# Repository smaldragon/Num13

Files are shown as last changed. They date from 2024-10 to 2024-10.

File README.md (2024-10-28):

# Num13

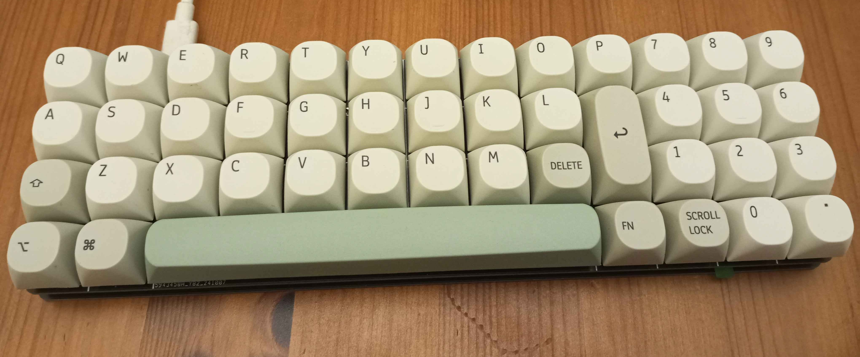
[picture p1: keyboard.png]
Photo of the keyboard in person


**Num13** is a 45-key compact ortholinear mechanical keyboard which includes a **Num**pad and is **13**Ux4U in size, which I designed for my own personal use.

The build is composed of 2 PCBs, the **top** pcb includes the key matrix (MX switches or low-profile Redragon switches w/ plate stabs), while the **bottom** includes the keyboard controller (a pi pico), a status led (rgb on the rB revision included here), and serves as the base of the keyboard structure itself.

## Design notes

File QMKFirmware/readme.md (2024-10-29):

# num13

num13

*A short description of the keyboard/project*

* Keyboard Maintainer: [smaldragon](https://github.com/smaldragon)
* Hardware Supported: *The PCBs, controllers supported*
* Hardware Availability: *Links to where you can find this hardware*

Make example for this keyboard (after setting up your build environment):

    make num13:default

Flashing example for this keyboard:

    make num13:default:flash

See the [build environment setup](https://docs.qmk.fm/#/getting_started_build_tools) and the [make instructions](https://docs.qmk.fm/#/getting_started_make_guide) for more information. Brand new to QMK? Start with our [Complete Newbs Guide](https://docs.qmk.fm/#/newbs).

## Bootloader

Enter the bootloader in 3 ways:

* **Bootmagic reset**: Hold down the key at (0,0) in the matrix (usually the top left key or Escape) and plug in the keyboard
* **Physical reset button**: Briefly press the button on the back of the PCB - some may have pads you must short instead
* **Keycode in layout**: Press the key mapped to `QK_BOOT` if it is available

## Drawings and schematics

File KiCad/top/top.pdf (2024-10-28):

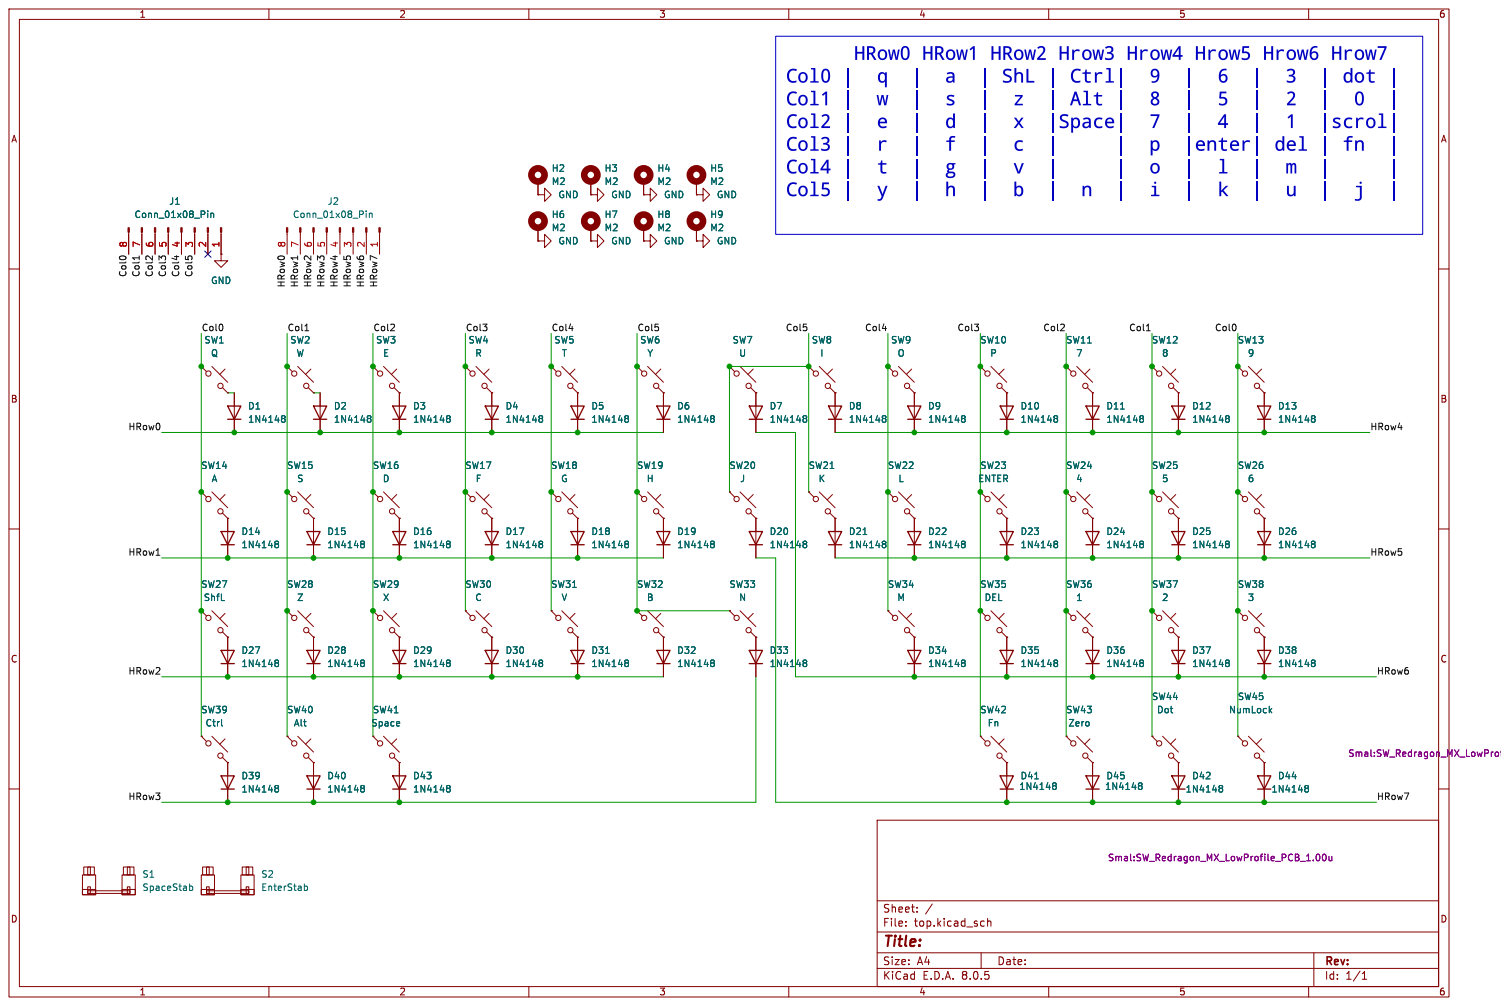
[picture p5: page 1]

Id: 1/1 Title: File: top.kicad_sch Sheet: /

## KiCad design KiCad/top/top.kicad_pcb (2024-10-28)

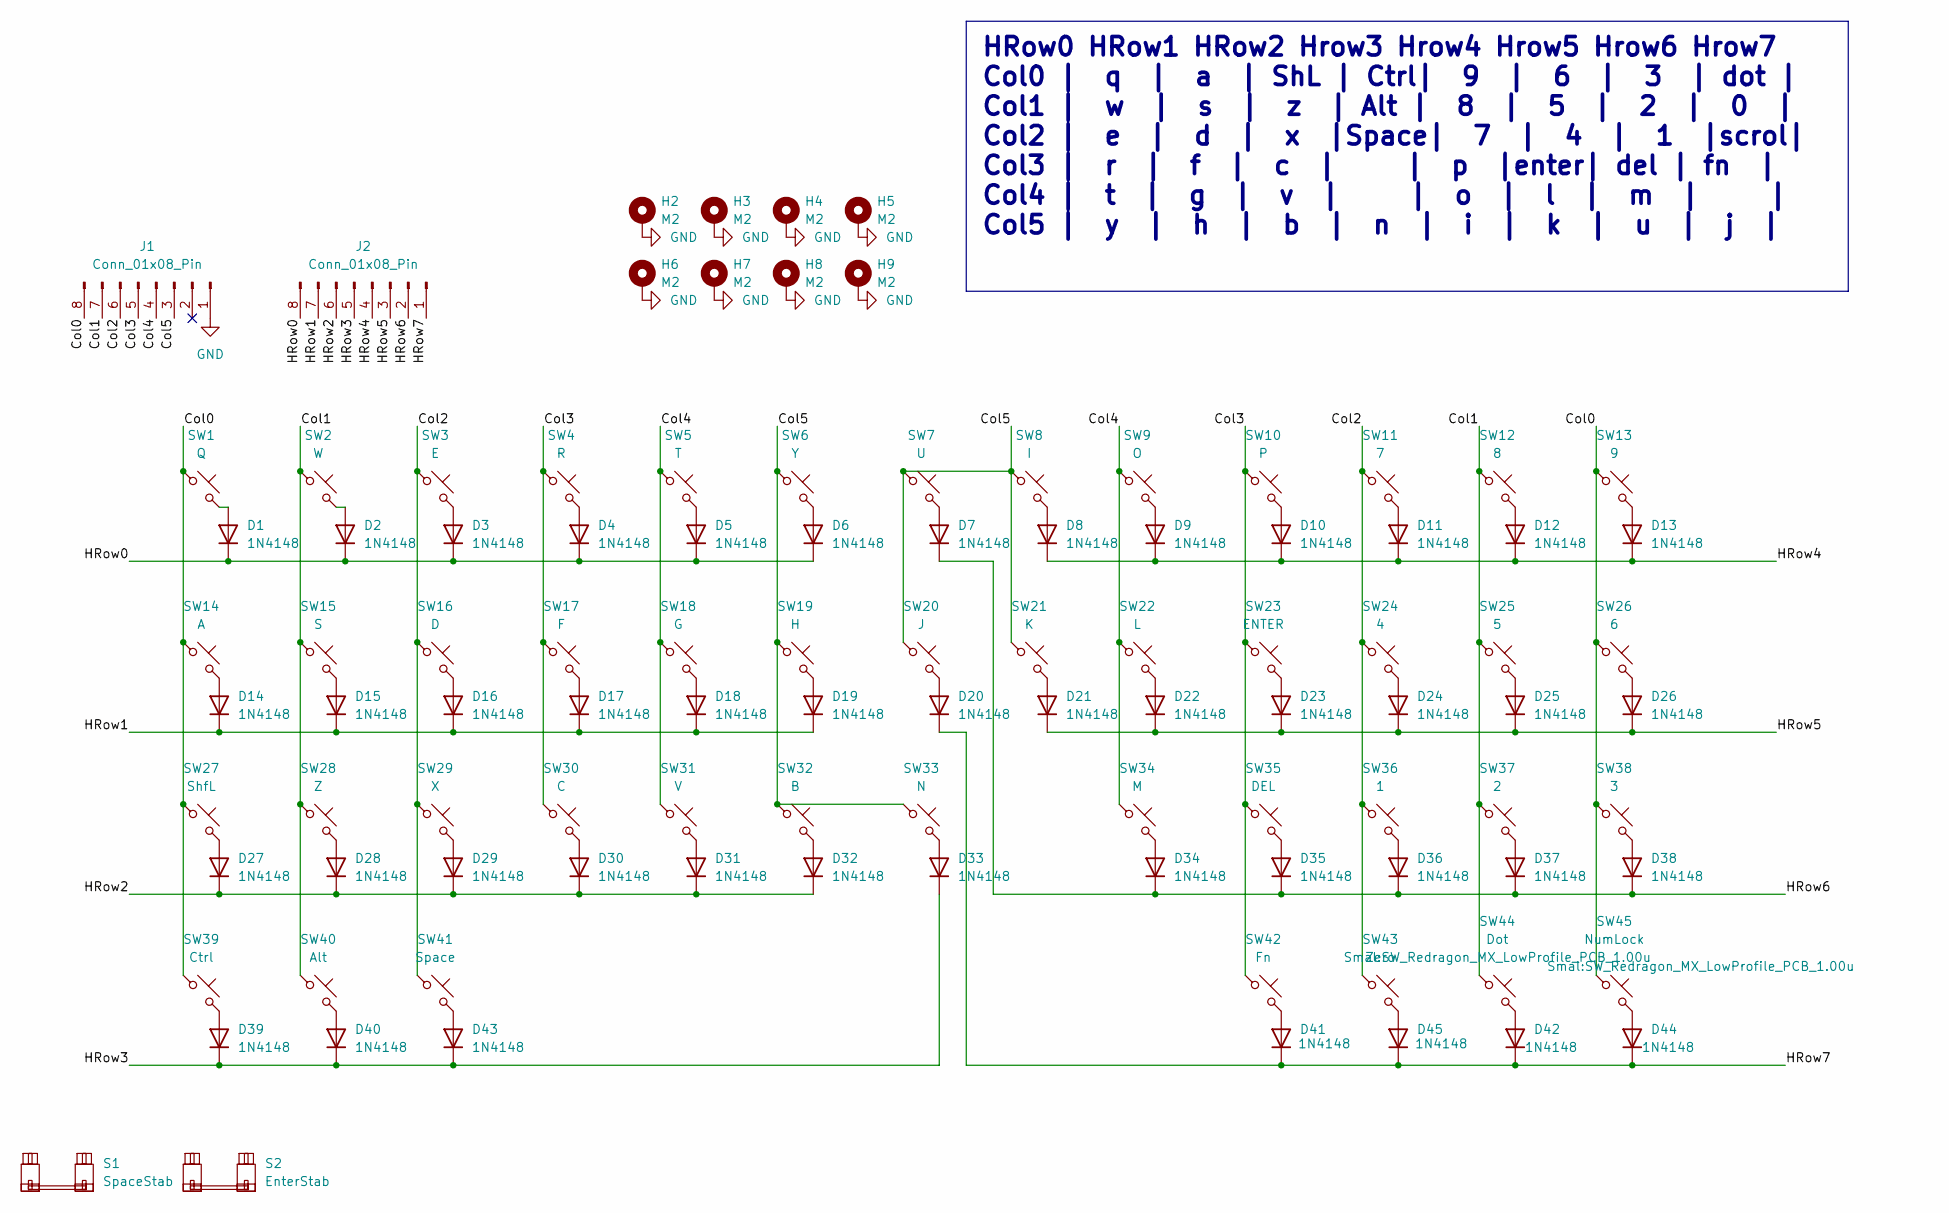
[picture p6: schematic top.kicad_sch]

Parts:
D1, D2, D3, D4, D5, D6, D7, D8, D9, D10, D11, D12, D13, D14, D15, D16, D17, D18, D19, D20, D21, D22, D23, D24, D25, D26, D27, D28, D29, D30, D31, D32, D33, D34, D35, D36, D37, D38, D39, D40, D41, D42, D43, D44, D45: 1N4148; D_DO-35_SOD27_P7.62mm_Horizontal
H2, H3, H4, H5, H6, H7, H8, H9: M2; MountingHole_2.2mm_M2_Pad
J1, J2: Conn_01x08_Pin; PinHeader_1x08_P2.54mm_Vertical
S1: SpaceStab; ks27_7u_pcb_cherry_plate
S2: EnterStab; ks27_2u_pcb_cherry_plate_stab
SW1: Q; SW_Redragon_MX_LowProfile_PCB_1.00u
SW2: W; SW_Redragon_MX_LowProfile_PCB_1.00u
SW3: E; SW_Redragon_MX_LowProfile_PCB_1.00u
SW4: R; SW_Redragon_MX_LowProfile_PCB_1.00u
SW5: T; SW_Redragon_MX_LowProfile_PCB_1.00u
SW6: Y; SW_Redragon_MX_LowProfile_PCB_1.00u
SW7: U; SW_Redragon_MX_LowProfile_PCB_1.00u
SW8: I; SW_Redragon_MX_LowProfile_PCB_1.00u
SW9: O; SW_Redragon_MX_LowProfile_PCB_1.00u
SW10: P; SW_Redragon_MX_LowProfile_PCB_1.00u
SW11: 7; SW_Redragon_MX_LowProfile_PCB_1.00u
SW12: 8; SW_Redragon_MX_LowProfile_PCB_1.00u
SW13: 9; SW_Redragon_MX_LowProfile_PCB_1.00u
SW14: A; SW_Redragon_MX_LowProfile_PCB_1.00u
SW15: S; SW_Redragon_MX_LowProfile_PCB_1.00u
SW16: D; SW_Redragon_MX_LowProfile_PCB_1.00u
SW17: F; SW_Redragon_MX_LowProfile_PCB_1.00u
SW18: G; SW_Redragon_MX_LowProfile_PCB_1.00u
SW19: H; SW_Redragon_MX_LowProfile_PCB_1.00u
SW20: J; SW_Redragon_MX_LowProfile_PCB_1.00u
SW21: K; SW_Redragon_MX_LowProfile_PCB_1.00u
SW22: L; SW_Redragon_MX_LowProfile_PCB_1.00u
SW23: ENTER; SW_Redragon_MX_LowProfile_PCB_2.00u
SW24: 4; SW_Redragon_MX_LowProfile_PCB_1.00u
SW25: 5; SW_Redragon_MX_LowProfile_PCB_1.00u
SW26: 6; SW_Redragon_MX_LowProfile_PCB_1.00u
SW27: ShfL; SW_Redragon_MX_LowProfile_PCB_1.00u
SW28: Z; SW_Redragon_MX_LowProfile_PCB_1.00u
SW29: X; SW_Redragon_MX_LowProfile_PCB_1.00u
SW30: C; SW_Redragon_MX_LowProfile_PCB_1.00u
SW31: V; SW_Redragon_MX_LowProfile_PCB_1.00u
SW32: B; SW_Redragon_MX_LowProfile_PCB_1.00u
SW33: N; SW_Redragon_MX_LowProfile_PCB_1.00u
SW34: M; SW_Redragon_MX_LowProfile_PCB_1.00u
SW35: DEL; SW_Redragon_MX_LowProfile_PCB_1.00u
SW36: 1; SW_Redragon_MX_LowProfile_PCB_1.00u
SW37: 2; SW_Redragon_MX_LowProfile_PCB_1.00u
SW38: 3; SW_Redragon_MX_LowProfile_PCB_1.00u
SW39: Ctrl; SW_Redragon_MX_LowProfile_PCB_1.00u
SW40: Alt; SW_Redragon_MX_LowProfile_PCB_1.00u
SW41: Space; SW_Redragon_MX_LowProfile_PCB_7.00u
SW42: Fn; SW_Redragon_MX_LowProfile_PCB_1.00u
SW43: Zero; SW_Redragon_MX_LowProfile_PCB_1.00u
SW44: Dot; SW_Redragon_MX_LowProfile_PCB_1.00u
SW45: NumLock; SW_Redragon_MX_LowProfile_PCB_1.00u

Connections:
/Col0: J1.8, SW1.1, SW13.1, SW14.1, SW26.1, SW27.1, SW38.1, SW39.1, SW45.1
/Col1: J1.7, SW2.1, SW12.1, SW15.1, SW25.1, SW28.1, SW37.1, SW40.1, SW44.1
/Col2: J1.6, SW3.1, SW11.1, SW16.1, SW24.1, SW29.1, SW36.1, SW41.1, SW43.1
/Col3: J1.5, SW4.1, SW10.1, SW17.1, SW23.1, SW30.1, SW35.1, SW42.1
/Col4: J1.4, SW5.1, SW9.1, SW18.1, SW22.1, SW31.1, SW34.1
/Col5: J1.3, SW6.1, SW7.1, SW8.1, SW19.1, SW20.1, SW21.1, SW32.1, SW33.1
/HRow0: D1.1 (K), D2.1 (K), D3.1 (K), D4.1 (K), D5.1 (K), D6.1 (K), J2.8
/HRow1: D14.1 (K), D15.1 (K), D16.1 (K), D17.1 (K), D18.1 (K), D19.1 (K), J2.7
/HRow2: D27.1 (K), D28.1 (K), D29.1 (K), D30.1 (K), D31.1 (K), D32.1 (K), J2.6
/HRow3: D33.1 (K), D39.1 (K), D40.1 (K), D43.1 (K), J2.5
/HRow4: D8.1 (K), D9.1 (K), D10.1 (K), D11.1 (K), D12.1 (K), D13.1 (K), J2.4
/HRow5: D21.1 (K), D22.1 (K), D23.1 (K), D24.1 (K), D25.1 (K), D26.1 (K), J2.3
/HRow6: D7.1 (K), D34.1 (K), D35.1 (K), D36.1 (K), D37.1 (K), D38.1 (K), J2.2
/HRow7: D20.1 (K), D41.1 (K), D42.1 (K), D44.1 (K), D45.1 (K), J2.1
GND: H2.1, H3.1, H4.1, H5.1, H6.1, H7.1, H8.1, H9.1, J1.1
unnamed: D1.2 (A), SW1.2
unnamed: D2.2 (A), SW2.2
unnamed: D3.2 (A), SW3.2
unnamed: D4.2 (A), SW4.2
unnamed: D5.2 (A), SW5.2
unnamed: D6.2 (A), SW6.2
unnamed: D7.2 (A), SW7.2
unnamed: D8.2 (A), SW8.2
unnamed: D9.2 (A), SW9.2
unnamed: D10.2 (A), SW10.2
unnamed: D11.2 (A), SW11.2
unnamed: D12.2 (A), SW12.2
unnamed: D13.2 (A), SW13.2
unnamed: D14.2 (A), SW14.2
unnamed: D15.2 (A), SW15.2
unnamed: D16.2 (A), SW16.2
unnamed: D17.2 (A), SW17.2
unnamed: D18.2 (A), SW18.2
unnamed: D19.2 (A), SW19.2
unnamed: D20.2 (A), SW20.2
unnamed: D21.2 (A), SW21.2
unnamed: D22.2 (A), SW22.2
unnamed: D23.2 (A), SW23.2
unnamed: D24.2 (A), SW24.2
unnamed: D25.2 (A), SW25.2
unnamed: D26.2 (A), SW26.2
unnamed: D27.2 (A), SW27.2
unnamed: D28.2 (A), SW28.2
unnamed: D29.2 (A), SW29.2
unnamed: D30.2 (A), SW30.2
unnamed: D31.2 (A), SW31.2
unnamed: D32.2 (A), SW32.2
unnamed: D33.2 (A), SW33.2
unnamed: D34.2 (A), SW34.2
unnamed: D35.2 (A), SW35.2
unnamed: D36.2 (A), SW36.2
unnamed: D37.2 (A), SW37.2
unnamed: D38.2 (A), SW38.2
unnamed: D39.2 (A), SW39.2
unnamed: D40.2 (A), SW40.2
unnamed: D41.2 (A), SW42.2
unnamed: D42.2 (A), SW44.2
unnamed: D43.2 (A), SW41.2
unnamed: D44.2 (A), SW45.2
unnamed: D45.2 (A), SW43.2

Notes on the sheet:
HRow0 HRow1 HRow2 Hrow3 Hrow4 Hrow5 Hrow6 Hrow7 Col0 | q | a | ShL | Ctrl| 9 | 6 | 3 | dot | Col1 | w | s | z | Alt | 8 | 5 | 2 | 0 | Col2 | e | d | x |Space| 7 | 4 | 1 |scrol| Col3 | r | f | c | | p |enter| del | fn | Col4 | t | g | v | | o | l | m | | Col5 | y | h | b | n | i | k | u | j |

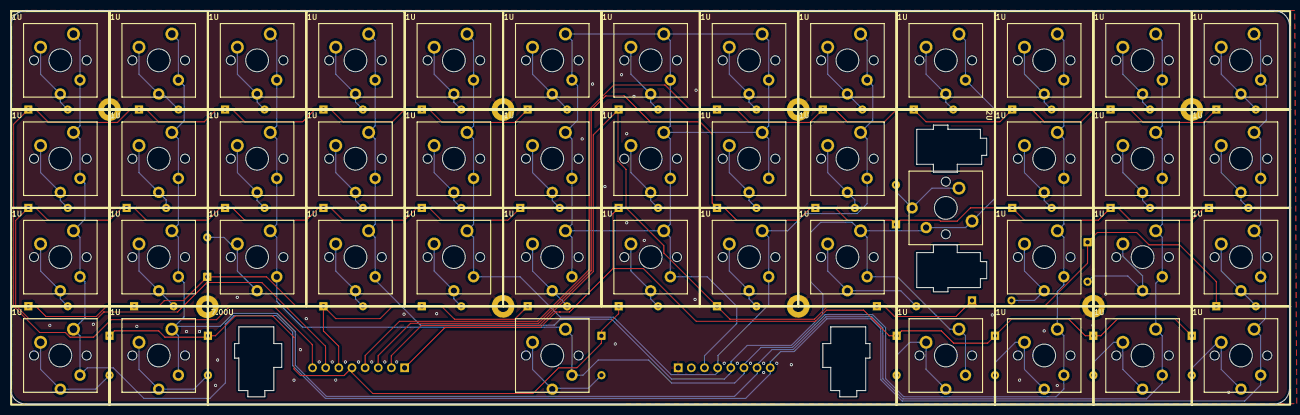
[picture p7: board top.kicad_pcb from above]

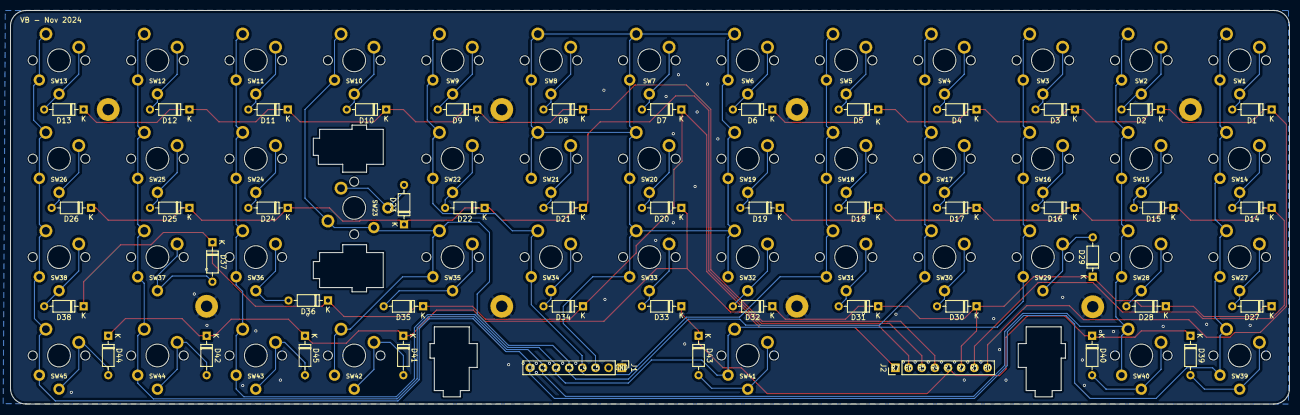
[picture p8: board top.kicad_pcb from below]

Board: 2 copper layers, 247.0 x 76.0 mm, 102 parts (47 on the bottom side), 60 nets.

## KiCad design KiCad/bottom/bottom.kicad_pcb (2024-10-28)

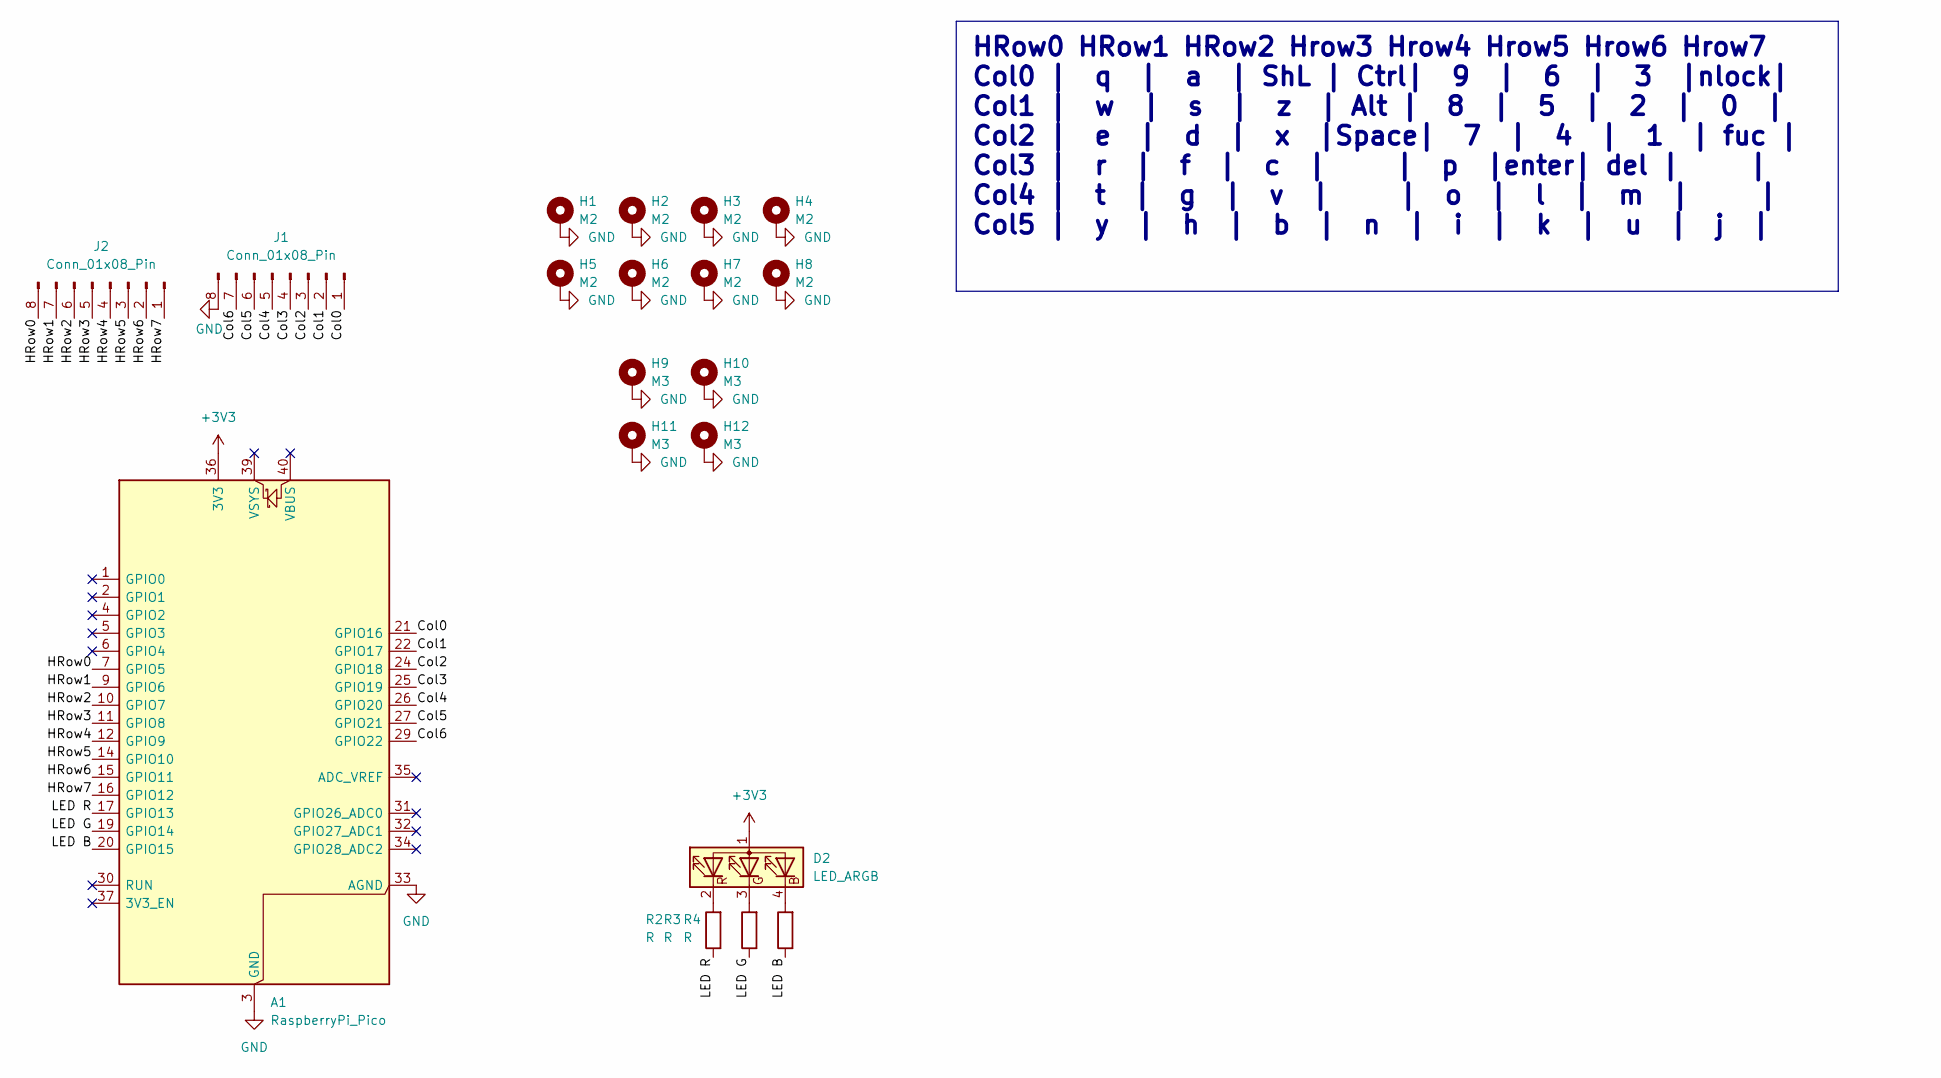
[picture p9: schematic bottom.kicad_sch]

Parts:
A1: RaspberryPi_Pico; RaspberryPi_Pico_Common_SMD
D2: LED_ARGB; ARGB horizontal
H1, H2, H3, H4, H5, H6, H7, H8: M2; MountingHole_2.2mm_M2_Pad
H9, H10, H11, H12: M3; MountingHole_3.2mm_M3_Pad
J1, J2: Conn_01x08_Pin; Harwin_M20-89008xx_1x08_P2.54mm_Horizontal
R2, R3, R4: R; R_0805_2012Metric

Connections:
+3V3: A1.36 (3V3), D2.1 (A)
/Col0: A1.21 (GPIO16), J1.1
/Col1: A1.22 (GPIO17), J1.2
/Col2: A1.24 (GPIO18), J1.3
/Col3: A1.25 (GPIO19), J1.4
/Col4: A1.26 (GPIO20), J1.5
/Col5: A1.27 (GPIO21), J1.6
/Col6: A1.29 (GPIO22), J1.7
/HRow0: A1.7 (GPIO5), J2.8
/HRow1: A1.9 (GPIO6), J2.7
/HRow2: A1.10 (GPIO7), J2.6
/HRow3: A1.11 (GPIO8), J2.5
/HRow4: A1.12 (GPIO9), J2.4
/HRow5: A1.14 (GPIO10), J2.3
/HRow6: A1.15 (GPIO11), J2.2
/HRow7: A1.16 (GPIO12), J2.1
/LED B: A1.20 (GPIO15), R4.1
/LED G: A1.19 (GPIO14), R3.1
/LED R: A1.17 (GPIO13), R2.1
GND: A1.3 (GND), A1.8 (GND), A1.13 (GND), A1.18 (GND), A1.23 (GND), A1.28 (GND), A1.33 (AGND), A1.38 (GND), H1.1, H2.1, H3.1, H4.1, H5.1, H6.1, H7.1, H8.1, H9.1, H10.1, H11.1, H12.1, J1.8
unnamed: D2.4 (BK), R4.2
unnamed: D2.3 (GK), R3.2
unnamed: D2.2 (RK), R2.2

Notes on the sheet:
HRow0 HRow1 HRow2 Hrow3 Hrow4 Hrow5 Hrow6 Hrow7 Col0 | q | a | ShL | Ctrl| 9 | 6 | 3 |nlock| Col1 | w | s | z | Alt | 8 | 5 | 2 | 0 | Col2 | e | d | x |Space| 7 | 4 | 1 | fuc | Col3 | r | f | c | | p |enter| del | | Col4 | t | g | v | | o | l | m | | Col5 | y | h | b | n | i | k | u | j |

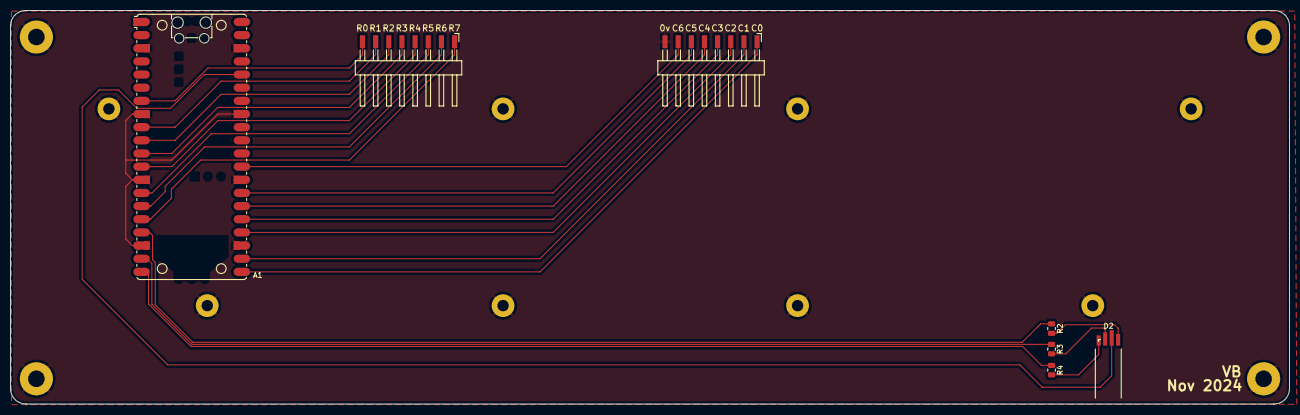
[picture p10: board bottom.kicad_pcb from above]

Board: 2 copper layers, 247.0 x 76.0 mm, 19 parts (0 on the bottom side), 23 nets.

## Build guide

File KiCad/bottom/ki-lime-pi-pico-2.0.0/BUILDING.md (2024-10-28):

**Instructions for building from source**
===========================================

> *Note that this project was largely leveraged for becoming more familiar with various aspects of KiCad, FreeCAD, and the Raspberry Pi Pico, and certain files may use exploratory workflows as a result.*

&nbsp;

# Development Environment

  Parametric models created in [FreeCAD 0.20.2](https://github.com/FreeCAD/FreeCAD/releases/tag/0.20.2) with the [KiCad StepUp 10.7.7](https://github.com/easyw/kicadStepUpMod/tree/5dfb0eb7093ab7f67d0f91c9bbae6fb78de93d46) workbench addon

  Exported VRML models modified in [VSCodium 1.74.3](https://github.com/VSCodium/vscodium/releases/tag/1.74.3.23010)

  KiCad symbols and footprints created using KiCad 6.0.10 through 8.0.3 and finalized using [KiCad 8.0.3](https://github.com/KiCad/kicad-source-mirror/releases/tag/8.0.3)

&nbsp;

# Symbols and Footprints

  KiCad symbols and footprints are already in the appropriate directories, so nothing needs to be done to prepare them for export.

&nbsp;

# Models

<details><summary>Regarding parametric colours</summary>
  
  > *Model faces are parametrically coloured via boolean operations between parts of varying diffuse colours.  To alter source colours for the board, see `Parametric_Source > Boards_Source > Parametric Board Colour Sources` in the `Tree view` panel and modify each Body's `Appearance`.  To alter source colours for components, be sure to modify the `Appearance` of the source Bodies **directly**, which are contained within the compounds/part containers in `Parametric_Source > Pico_Components_Source`.  Modifying the `Appearance` of the compounds/part containers or setting parts' face colours with `Set Colors...` will **not** parametrically populate.*
  >
  > *Note that as of FreeCAD 0.20.2 changing the sources of the colours does not automatically populate down all the dependent objects.  To get around this if you make any colour changes, when you are ready to export be sure to recompute the entire document as detailed below.  This should successfully populate the parametric colours across all dependent objects.*
  
</details>

  ### General

  - Open the models source file at `.../ki-lime-pi-pico/models/RaspberryPi_Pico_Variations.FCStd` in FreeCAD

  - In FreeCAD's `Tree view` panel, `right-click` on the root document name `RaspberryPi_Pico_Variations` and select `Mark to recompute`

  - Click `Edit > Refresh` (or press `F5`) to recompute the entire document

  ### VRML

  - Enter the KiCad StepUp addon workbench from the drop-down menu at the top of the window

  - In FreeCAD's `Tree view` panel, locate the contents of the folder `Export > KiCad Model Outputs > VRML - Manually Coloured Clones`

  - Select the `Clone` you wish to export to a VRML file for KiCad (for example: `RaspberryPi_Pico`)
    <details><summary>Additional information regarding clones and colours</summary>
      
      > *KiCad StepUp provides a selection of fully-featured materials that can be exported to VRML files.  Although the selection is limited, it provides convenient labelling of materials that can be edited later.  I have created `Clones` of each variation (which as of FreeCAD 0.20.2 do **not** parametrically preserve colour) and pre-set each face colour to align with colours defined within KiCad StepUp.*
      >
      > *Note that if you change geometry in any way which alters the number or topological location of faces anywhere within the model, these pre-set `Clones` will no longer be coloured appropriately*
      >
      > *You can always export from the parametrically coloured `Compounds` in `Export > KiCad Model Outputs > STEP - Parametrically Coloured Compounds`, just needing to set the export colours in KiCad StepUp each time as they will be reset upon recomputes.*
      
    </details>

  - Click on KiCad StepUp's `Export 3D Model` button (a graphic of a black 6-pin IC with a green arrow pointing down and to the right)

  - When prompted, I have used the default `Mesh Deviation` and `creaseAngle` and I find the results to be acceptable

  - Accept all the KiCad StepUp colour association prompts

    > *Note that if you have recreated these `Clones` due to geometric changes, you will need to manually set these colour associations.  These instructions assume you are using the originally associated KiCad StepUp face colours*

  - Repeat this for all `Clones`

  - Prepare a powerful text editor for bulk file editing

    <details> <summary> Specific instructions for preparing VSCodium/VSCode</summary>

      - Open a new VSCode-based instance

      - Select `File > Open Folder...`

      - Navigate to the directory `.../ki-lime-pi-pico/`

      - Select the folder `models/` and click `Select Folder`

      - Open each `.wrl` file by `double-clicking` each file in the `Explorer` pane

      - Select the magnifying glass on the left to open the `Search` pane

      - Expand the search box with the arrow to its left to reveal its find-and-replace functionality

      - Click the `...` in the bottom-right of the find-and-replace fields to expand additional options

      - Select the graphic of an open book in the `files to include` field to only process files which are currently open

    </details>

  - Find and replace the following material names in the newly created `.wrl` files:

    > *Be sure **not** to replace these material names in `MaterialsList.txt`!*

    | Original material   | Replace with
    |:-------------------:|:------------:
    | `PLASTIC-YELLOW-01` | `FINISH-GOLD`
    | `MET-SILVER`        | `FINISH-SILVER`
    | `RES-SMD-01`        | `IC-BODY-EPOXY-02`
    | `CAP-CERAMIC-06`    | `CAP-CERAMIC-01`
    | `MET-01`            | `FINISH-TIN`
    | `IC-LABEL-01`       | `BOARD-FR4-NATURAL`
    | `BOARD-GREEN-02`    | `MASK-PINE-GREEN`
    | `RES-THT-01`        | `MASK-LIGHT-TAN`
    | `LED-WHITE`         | `LED-LENS-CLEAR`
    | `PLASTIC-GREEN-01`  | `EMISSIVE-GREEN-PHOSPHOR`
  ##  
  - Finally, replace the default KiCad StepUp material definitions at the start of each `.wrl` file with the expanded list of materials found in `MaterialsList.txt`

    > *In VSCode-based editors, selecting `Match Case` in the search allows for the large blocks of material definition text to successfully be found and replaced*

    ---

  &nbsp;

  > *KiCad StepUp will automatically generate STEP files with limited hierarchy, part naming, and colour information as a result of the process above, so next we will export STEP models with more detailed information.*

  > *As of the time of writing, KiCad does not appropriately handle exporting part face colours when the component's STEP file uses assemblies.  To get around this, we will export our STEP models as `Compounds` for KiCad.  This will still result in limited hierarchy and part naming information, but will at least preserve face colours (excluding transparency) and discrete sub-components.*

  ### STEP (for KiCad)

  - In FreeCAD's `Tree view` panel, shift focus to the contents of the folder `Export > KiCad Model Outputs > STEP - Parametrically Coloured Compounds`

  - Manually select the root body you wish to export (for example: `RaspberryPi_Pico_Compound`)

  - Press `Ctrl + E`, or select `File > Export`

  - For ease, ensure the directory matches where KiCad StepUp exported its files to:
    `.../ki-lime-pi-pico/models/`

  - Ensure file type `"STEP with colors (*.step *.stp)"` is selected

  - Select the name of the already-generated model you intend to replace (for example: `RaspberryPi_Pico.step`)

  - Select `Save`, and select `Yes` when asked to replace the existing file

  - Repeat this for all models

  - Once all 3D models have been exported as `.wrl` and `.step` files, navigate to:

  ```
  .../ki-lime-pi-pico/models/
  ```

  - And **copy** (don't remove!) all `.wrl` and `.step` files to:

  ```
  .../ki-lime-pi-pico/kicad/project-libraries/RaspberryPi_Pico/Module_RaspberryPi_Pico.3dshapes/
  ```

  ---
  > *In addition to these KiCad models, we can also export a second set of STEP files to a supplemental directory, in the event any users have a need for the fully-featured assemblies.  Feel free to skip this section if all you need is a standalone KiCad library.*

  ### STEP (fully featured supplement)

  - In FreeCAD's `Tree view` panel, navigate into the folder `Export > STEP Assembly`

  - Manually select the root body you wish to export (for example: `RaspberryPi_Pico_STEP`)

  - Press `Ctrl + E`, or select `File > Export`

  - For ease, ensure again the directory matches where KiCad StepUp exported its files to:
    `.../ki-lime-pi-pico/models/`

  - Ensure file type `"STEP with colors (*.step *.stp)"` is selected

  - Select the name of the already-generated model you intend to replace again (for example: `RaspberryPi_Pico.step`)

  - Select `Save`, and select `Yes` when asked to replace the existing file

    > *As a result of using empty `Group` folders as a source of parametric part/feature naming, exporting these parts will result in an expected warning in the `Report view`.*

  - Repeat this for all models

  - Once these 3D models have been exported as `.step` files, navigate to:
  ```
  .../ki-lime-pi-pico/models/
  ```

  - And copy all `.step` files to:

  ```
  .../ki-lime-pi-pico/models/RaspberryPi_Pico_STEP/
  ```

  ### File cleanup

  - Navigate to `.../ki-lime-pi-pico/models/`

  - Delete the previously copied `.wrl` and `.step` files, as they are no longer needed in this directory

&nbsp;

# Final recommendations

As desired, navigate to our source's root directory:

```
.../ki-lime-pi-pico/
```

Append, replace, or otherwise modify files such as `LICENSE.txt`, `ATTRIBUTION.md`, and `README.md` to appropriately reflect your needs.

Copy the desired files *(for example, I include all three of `LICENSE.txt`, `ATTRIBUTION.md`, and `README.md` with the final build)* to:

```
.../ki-lime-pi-pico/kicad/project-libraries/RaspberryPi_Pico/
```

*I prefer to remove the references to images in the built library's `README.md` once it's copied here to keep it clean and compact.*

If you are also exporting the fully-featured supplemental STEP models, copy the desired files *(for example, I include `LICENSE.txt` and `ATTRIBUTION.md`)* to:

```
.../ki-lime-pi-pico/models/RaspberryPi_Pico_STEP/
```

&nbsp;

# **All done!** 🎉

Your completed library to reference, copy, and distribute as you wish can be found at:

```
.../ki-lime-pi-pico/kicad/project-libraries/RaspberryPi_Pico/
```
